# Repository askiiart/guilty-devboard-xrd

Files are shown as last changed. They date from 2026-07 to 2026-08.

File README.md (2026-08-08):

# Guilty Devboard Xrd

A dev board for my keyboard, because all the options kinda suck

- Compatible with both XIAO nRF52840 Plus and nRF54LM20A
- As efficient as possible
- Fast battery charging (configurable ~50-700mA) and over(dis)charge protection
- Up to 5V 3A from USB, and 3.3V 1A (including MCU power draw)
- 27 GPIO pins, nearly as much as the XIAO nRF54LM20A, despite much more limited manufacturing capabilities, while still having an antenna built-in.

See the documentation for more details on what this has over the official XIAOs.

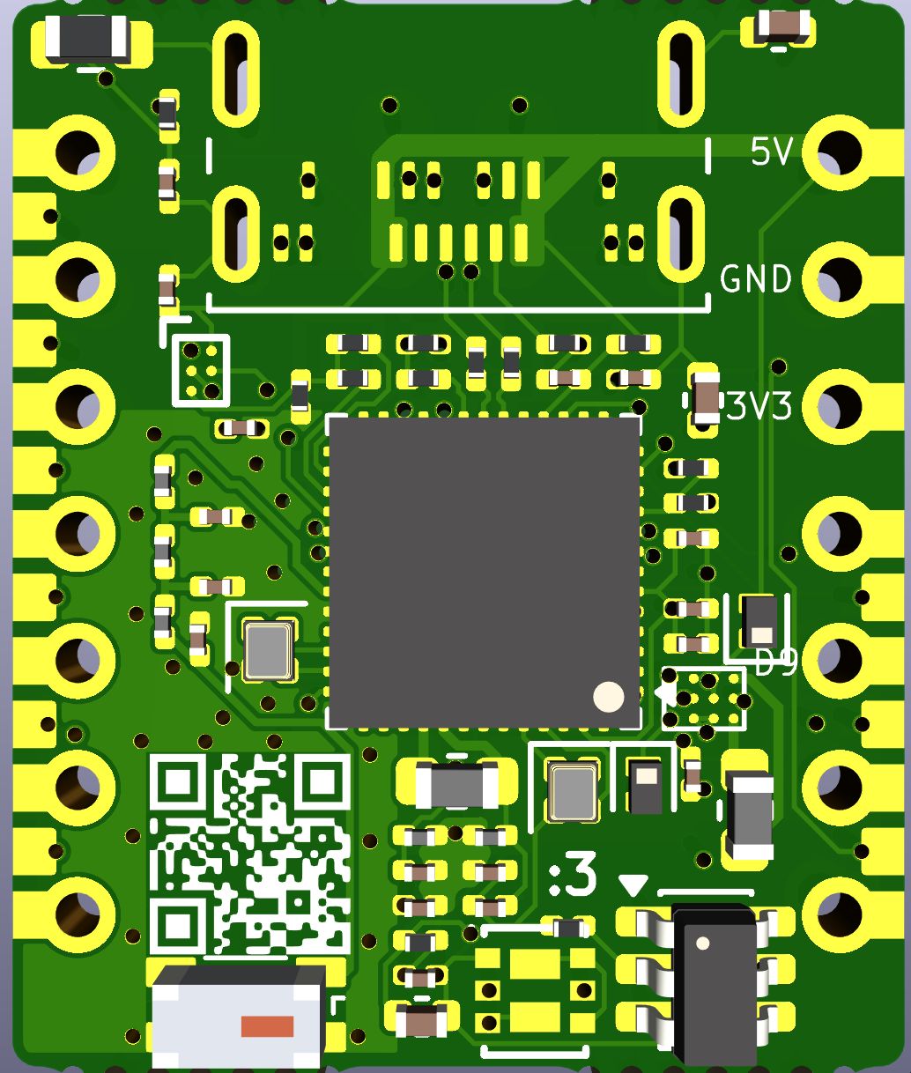
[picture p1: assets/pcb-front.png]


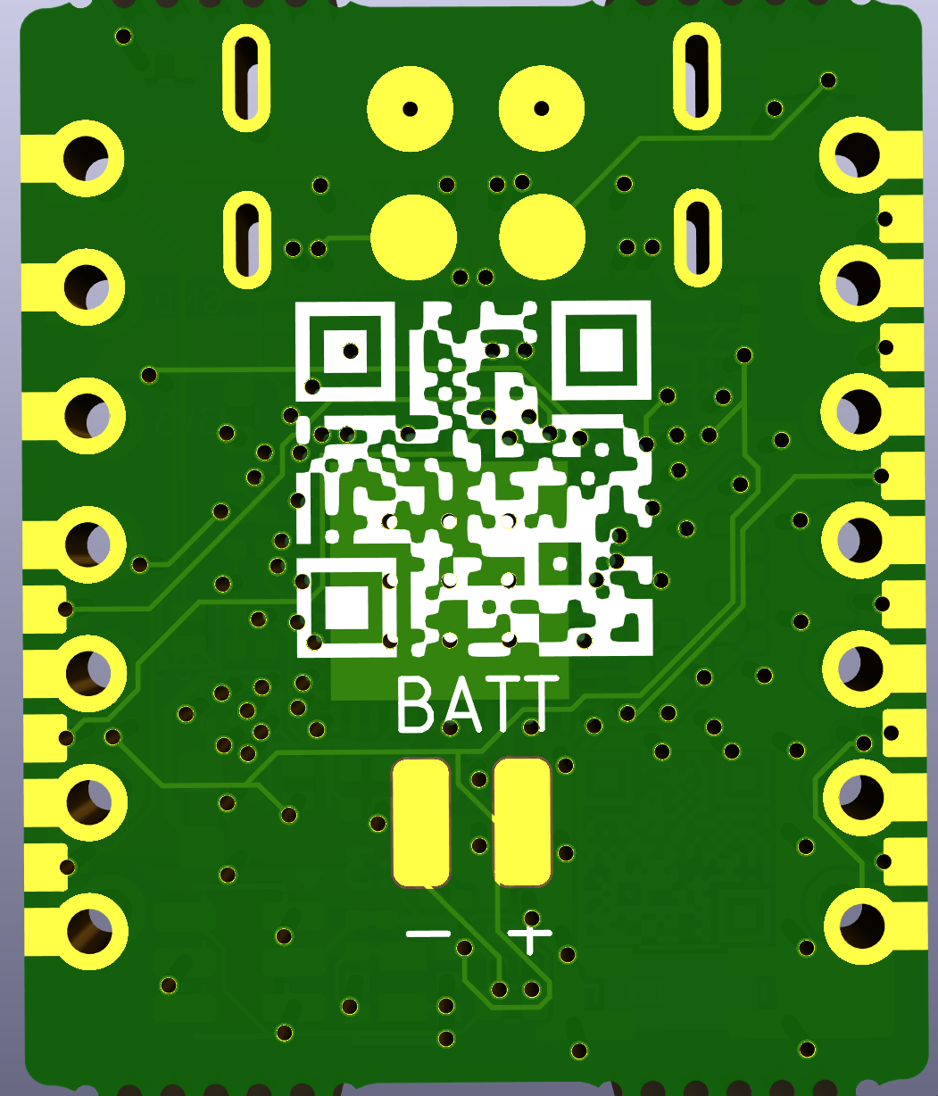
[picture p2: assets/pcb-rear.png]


## Documentation

Docs are available [here](https://askiiart.net/docs/guilty-devboard-xrd.html) ([short link](http://7qq.uk/xrd))

## Note: DRC errors

DRC shows ~140 clearance errors due to the Xiao Plus footprint having pads at and past the edge of the board, a couple things in the keep-out zone, and the QR codes overlapping/being too close to other items. That's intentional, ignore those.

## Schematic

Use Kicanvas to see the [schematic](https://kicanvas.org/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)

## Bill of Materials

|Name |Quantity needed|MOQ|Price |Quantity to order|Link |Total |
|---|---|---|---|---|---|---|
|Diodes |2 |20 |0.0257|20 |<https://www.lcsc.com/product-detail/C2912031.html> |0.514 |
|Ferrite bead |2 |50 |0.025 |50 |<https://www.lcsc.com/product-detail/C525479.html> |1.25 |
|MOSFETs |1 |10 |0.0434|10 |<https://www.lcsc.com/product-detail/C41355091.html> |0.434 |
|100nF cap |5 |50 |0.0018|50 |<https://www.lcsc.com/product-detail/C2903664.html> |0.09 |
|4.7uF cap |4 |10 |0.0733|10 |<https://www.lcsc.com/product-detail/C335103.html> |0.733 |
|1pF cap |1 |100|0.0024|100 |<https://www.lcsc.com/product-detail/C85894.html> |0.24 |
|2.2uF cap |2 |50 |0.0346|50 |<https://www.lcsc.com/product-detail/C335106.html> |1.73 |
|10uF cap |1 |20 |0.0368|20 |<https://www.lcsc.com/product-detail/C76991.html> |0.736 |
|1.5pF cap |1 |100|0.003 |100 |<https://www.lcsc.com/product-detail/C284990.html> |0.3 |
|22uF cap |2 |5  |0.1522|5 |<https://www.lcsc.com/product-detail/C7432764.html> |0.761 |
|470nF cap |1 |100|0.0057|100 |<https://www.lcsc.com/product-detail/C326573.html> |0.57 |
|1.2pF cap |1 |100|0.0016|100 |<https://www.lcsc.com/product-detail/C22374839.html> |0.16 |
|3.3nF inductor |1 |100|0.0073|100 |<https://www.lcsc.com/product-detail/C98045.html> |0.73 |
|1.5uH inductor |1 |50 |0.0111|50 |<https://www.lcsc.com/product-detail/C2885839.html> |0.555 |
|4.7nH inductor |1 |100|0.0099|100 |<https://www.lcsc.com/product-detail/C86126.html> |0.99 |
|3.6nH inductor |1 |20 |0.0322|20 |<https://www.lcsc.com/product-detail/C237447.html> |0.644 |
|4.7uH inductor |1 |1  |0.2829|1 |<https://www.lcsc.com/product-detail/C7261423.html> |0.2829 |
|1nH inductor |1 |100|0.0029|100 |<https://www.lcsc.com/product-detail/C46607389.html> |0.29 |
|5.1k resistor |2 |100|0.0007|100 |<https://www.lcsc.com/product-detail/C473460.html> |0.07 |
|470k resistor |1 |100|0.0013|100 |<https://www.lcsc.com/product-detail/C54530578.html> |0.13 |
|30 ohm resistor |2 |100|0.0008|100 |<https://www.lcsc.com/product-detail/C320826.html> |0.08 |
|2k resistor |1 |100|0.0021|100 |<https://www.lcsc.com/product-detail/C138107.html> |0.21 |
|1k resistor |1 |100|0.001 |100 |<https://www.lcsc.com/product-detail/C131396.html> |0.1 |
|806k resistor |1 |100|0.0009|100 |<https://www.lcsc.com/product-detail/C474840.html> |0.09 |
|2M resistor |1 |100|0.0006|100 |<https://www.lcsc.com/product-detail/C138106.html> |0.06 |
|10k resistor |1 |100|0.001 |100 |<https://www.lcsc.com/product-detail/C138117.html> |0.1 |
|220k resistor |1 |100|0.003 |100 |<https://www.lcsc.com/product-detail/C142020.html> |0.3 |
|68k resistor |1 |100|0.003 |100 |<https://www.lcsc.com/product-detail/C274345.html> |0.3 |
|2.2 ohm resistor |1 |100|0.0037|100 |<https://www.lcsc.com/product-detail/C473517.html> |0.37 |
|200 ohm resistor |1 |100|0.0011|100 |<https://www.lcsc.com/product-detail/C304517.html> |0.11 |
|SGM40567 |1 |1  |0.53  |1 |<https://www.lcsc.com/product-detail/C5141336.html> |0.53 |
|FH9261-G3JH |1 |20 |0.0289|20 |<https://www.lcsc.com/product-detail/C19273258.html> |0.578 |
|BD83070GWL-E2 |1 |1  |0.7198|1 |<https://www.lcsc.com/product-detail/C2071126.html> |0.7198 |
|32MHz crystal |1 |5  |1.0134|1 |<https://www.lcsc.com/product-detail/C5203637.html> |1.0134 |
|32.768kHz crystal |1 |1  |3.0197|1 |<https://www.lcsc.com/product-detail/C2595065.html> |3.0197 |
| | | | | | | |
|2450AT18D0100001E |1 |1  |0.57  |1 |<https://www.digikey.com/en/products/detail/johanson-technology-inc/2450AT18D0100001E/4770685> |0.57 |
| | | | | | | |
|NRF54LM20A-QGAA-R |1 |1  |6.7 |1 |<https://mou.sr/44t4RAm> |6.7 |
|Amphenol 124019772112A (USB-C)|1 |1  |2.41  |1 |<https://www.mouser.com/ProductDetail/Amphenol-Commercial-Products/124019772112A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>|2.41 |
| | | | | | | |
|JLCPCB | | | | | |$15.10 |
| | | | | | | |
|JLCPCB shipping | | | | |Roughly |$9.79 |
|Digikey shipping | | | | | |$4.99 |
|LCSC shipping | | | | | |7.25 |
|Mouser shipping | | | | | |8.49 |
|Mouser estimated tariffs | | | | | |0.24 |
| | | | | | | |
|Subtotal | | | | | |74.3308  |
|Total | | | | | |80.463091|

## Production notes

The layer stackup should be JLC0616H-3313, and a stencil with electropolishing is recommended.

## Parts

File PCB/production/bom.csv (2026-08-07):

Designator | Footprint | Quantity | Value | LCSC Part #
AE1 | 2450AT18D0100001E_L | 1 | Antenna_Chip
C1 | 0402 | 1 | 10uF
C11, C14, C17, C4 | 0201 | 4 | 4.7uF
C12 | 0201 | 1 | 0.1uF
C13, C6 | 0201 | 2 | 2.2uF
C15 | 0201 | 1 | 1.5pF
C16, C19 | 0402 | 2 | 22uF
C18 | 0201 | 1 | 1.2pF
C2, C21, C8, C9 | 0201 | 4 | 100nF
C23 | 0201 | 1 | 0.47uF
C3, C7 | 0201 | 2 | DNP
C5 | 0201 | 1 | 1.0pF
D6, D7 | D_SOD-882 | 2 | D
FB1, FB2 | 0201 | 2 | FerriteBead
J1 | USB_C_Receptacle_Amphenol_124019772112A | 1 | USB_C_Receptacle_USB2.0_16P
JP1 | 0603 | 1 | Jumper_2_Open
L1 | 0201 | 1 | 3.3nH
L3 | 0603 | 1 | 1.5uH
L4 | 0201 | 1 | 4.7nH
L5 | 0201 | 1 | 3.6nH
L6 | 0402 | 1 | 4.7uH
L7 | 0201 | 1 | 1.0nH
Q1 | PDFN-6_L2.0-W2.0-P0.65-BL-EP-1 | 1 | SP2038CNQ | C41355091
R1, R2 | 0201 | 2 | 5.1k
R12 | 0201 | 1 | 10k
R14 | 0201 | 1 | 220k
R15 | 0201 | 1 | 68k
R16 | 0201 | 1 | 2.2
R17 | 0201 | 1 | 200
R3 | 0201 | 1 | 470k
R4, R5 | 0201 | 2 | 30
R6 | 0201 | 1 | 2k
R7 | 0201 | 1 | 1k
R8 | 0201 | 1 | 806k
R9 | 0201 | 1 | 2M
U1 | QFN-52-1EP_6x6mm_P0.4mm_EP4.7x4.7mm_ThermalVias | 1 | nRF54LM20A-QGAA
U2 | WLCSP-6_L1.2-W0.9-R3-C2-P0.40-TL | 1 | SGM40567-4.2XG/TR | C5141336
U4 | TCA9536 | 1 | TCA9536
U5 | SOT-23-6 | 1 | FH9261-G3JH
U6 | BD83070GWL | 1 | BD83070GWL-E2
Y1 | Crystal_SMD_1210-4Pin_1.2x1.0mm | 1 | 32MHz
Y2 | Crystal_SMD_1210-4Pin_1.2x1.0mm | 1 | 32.768kHz

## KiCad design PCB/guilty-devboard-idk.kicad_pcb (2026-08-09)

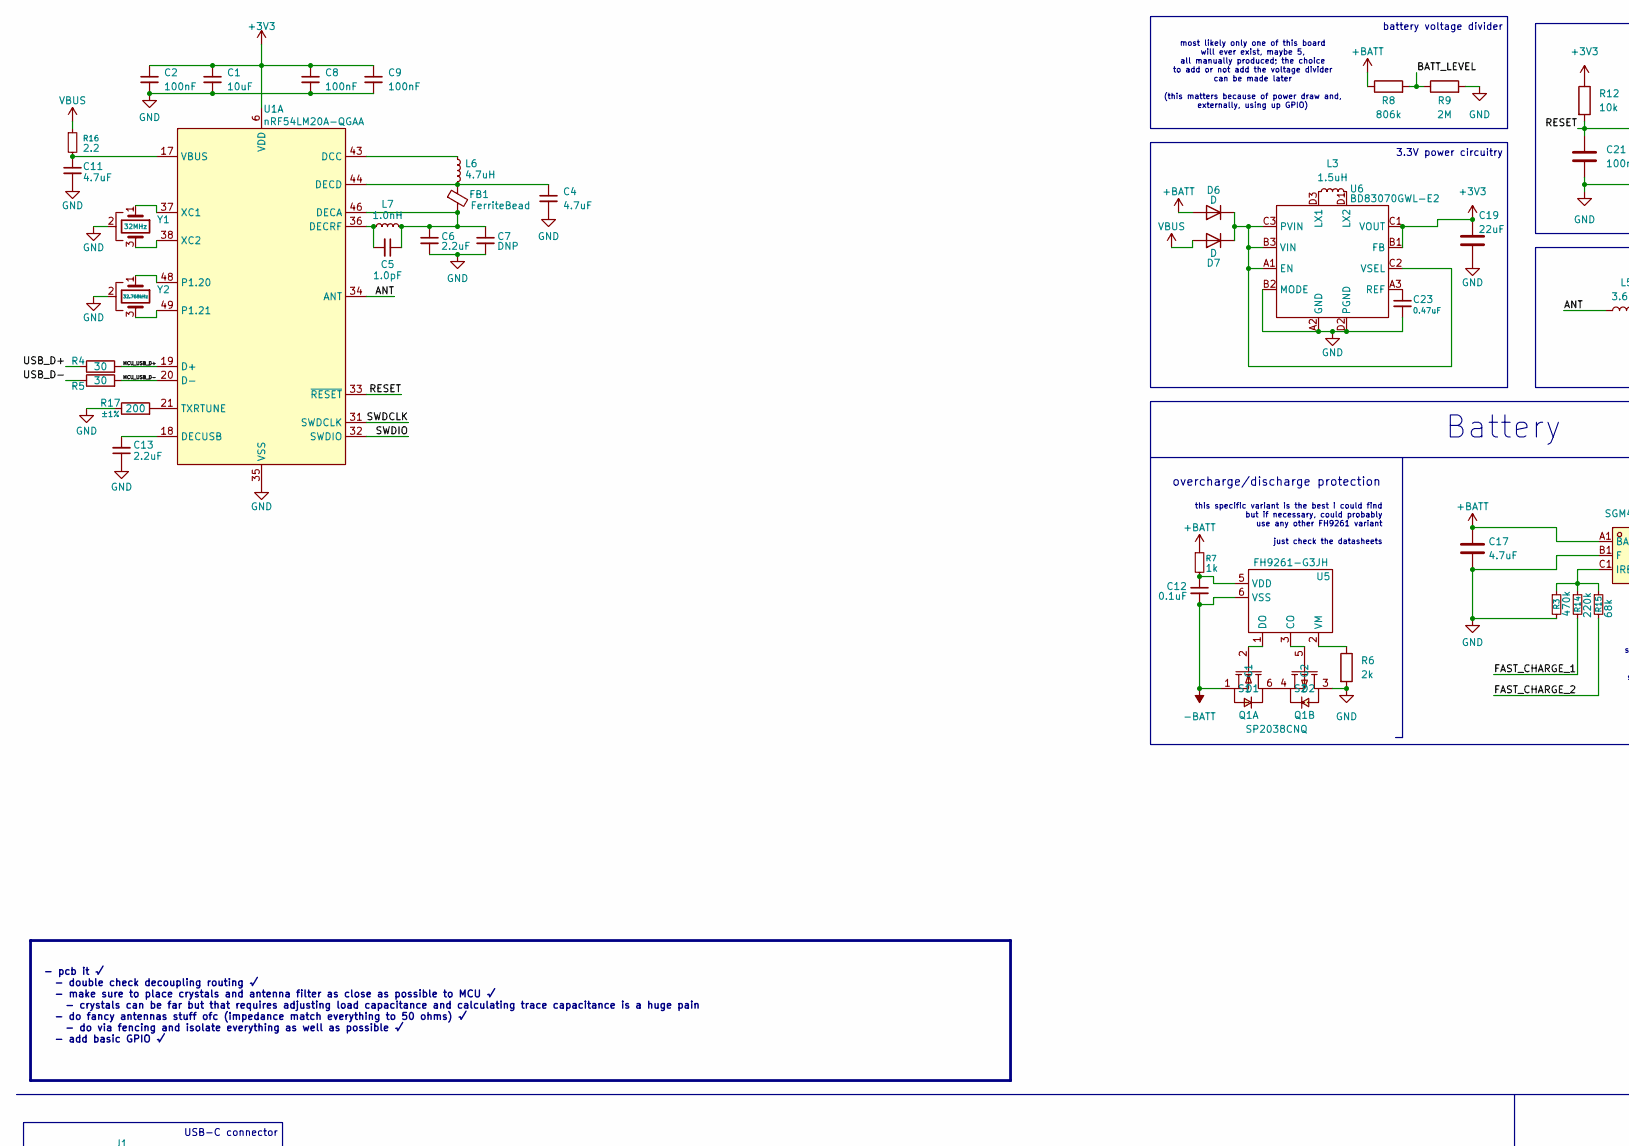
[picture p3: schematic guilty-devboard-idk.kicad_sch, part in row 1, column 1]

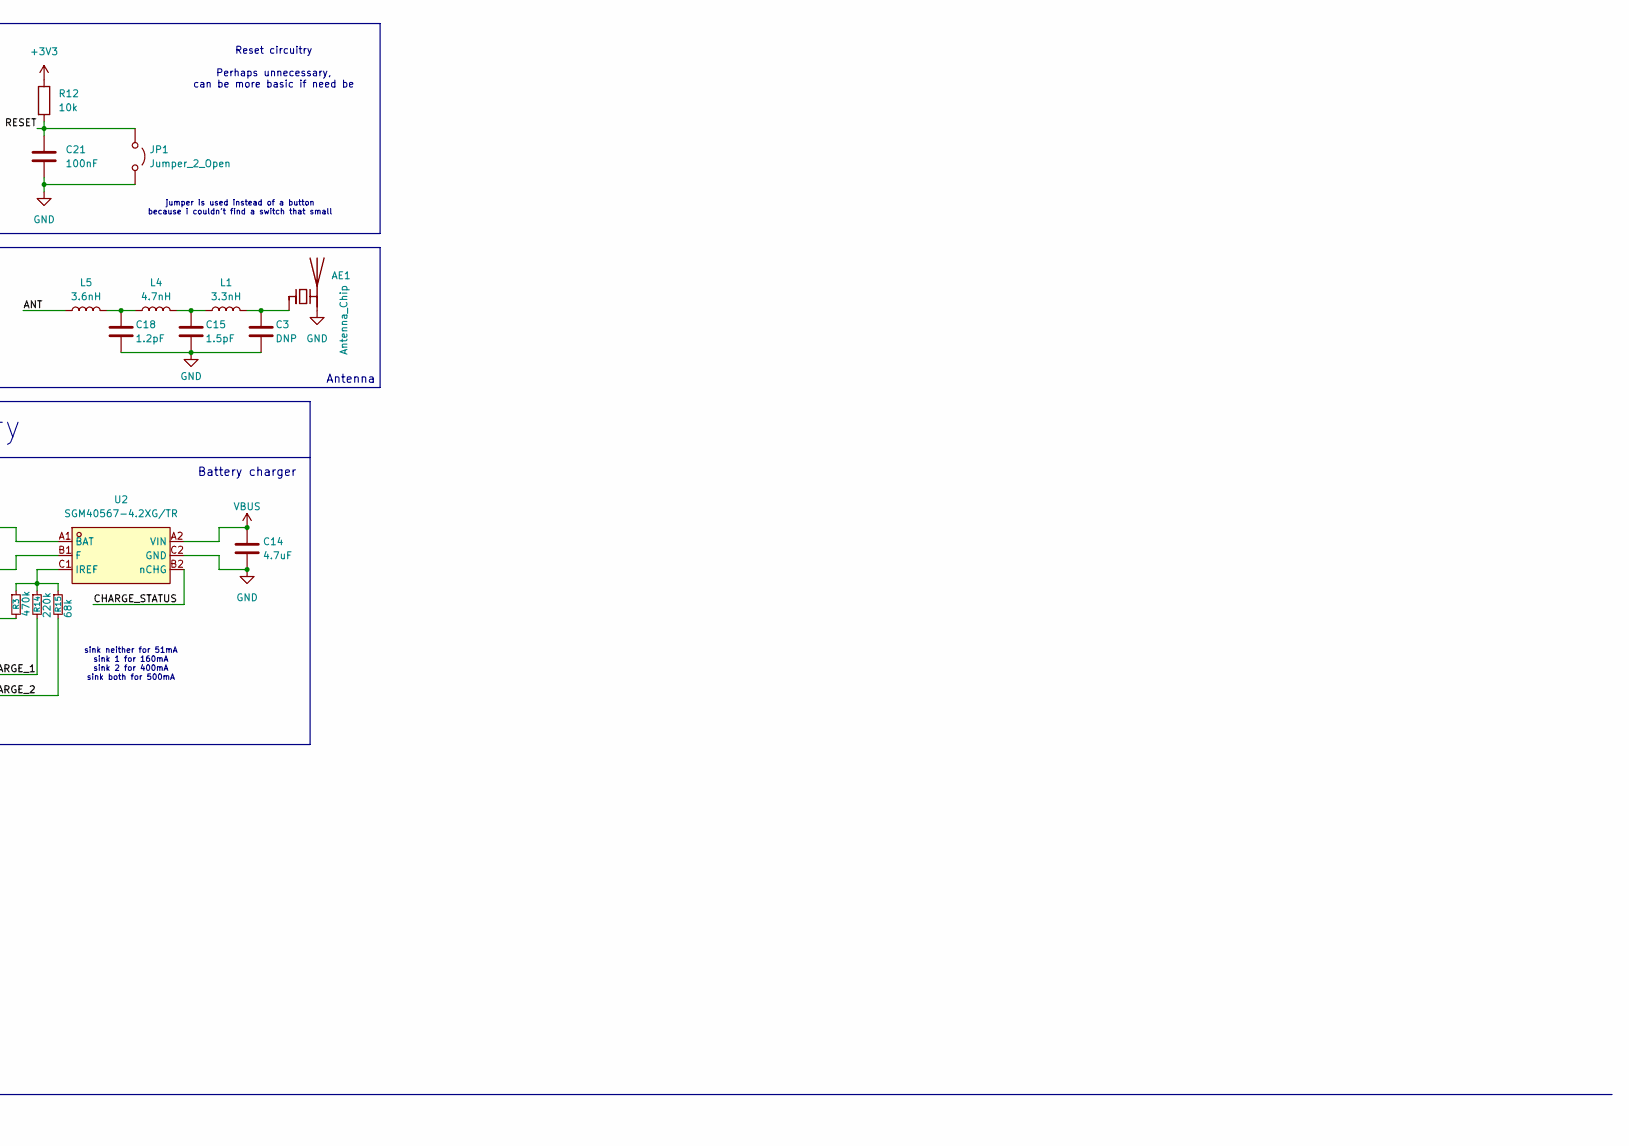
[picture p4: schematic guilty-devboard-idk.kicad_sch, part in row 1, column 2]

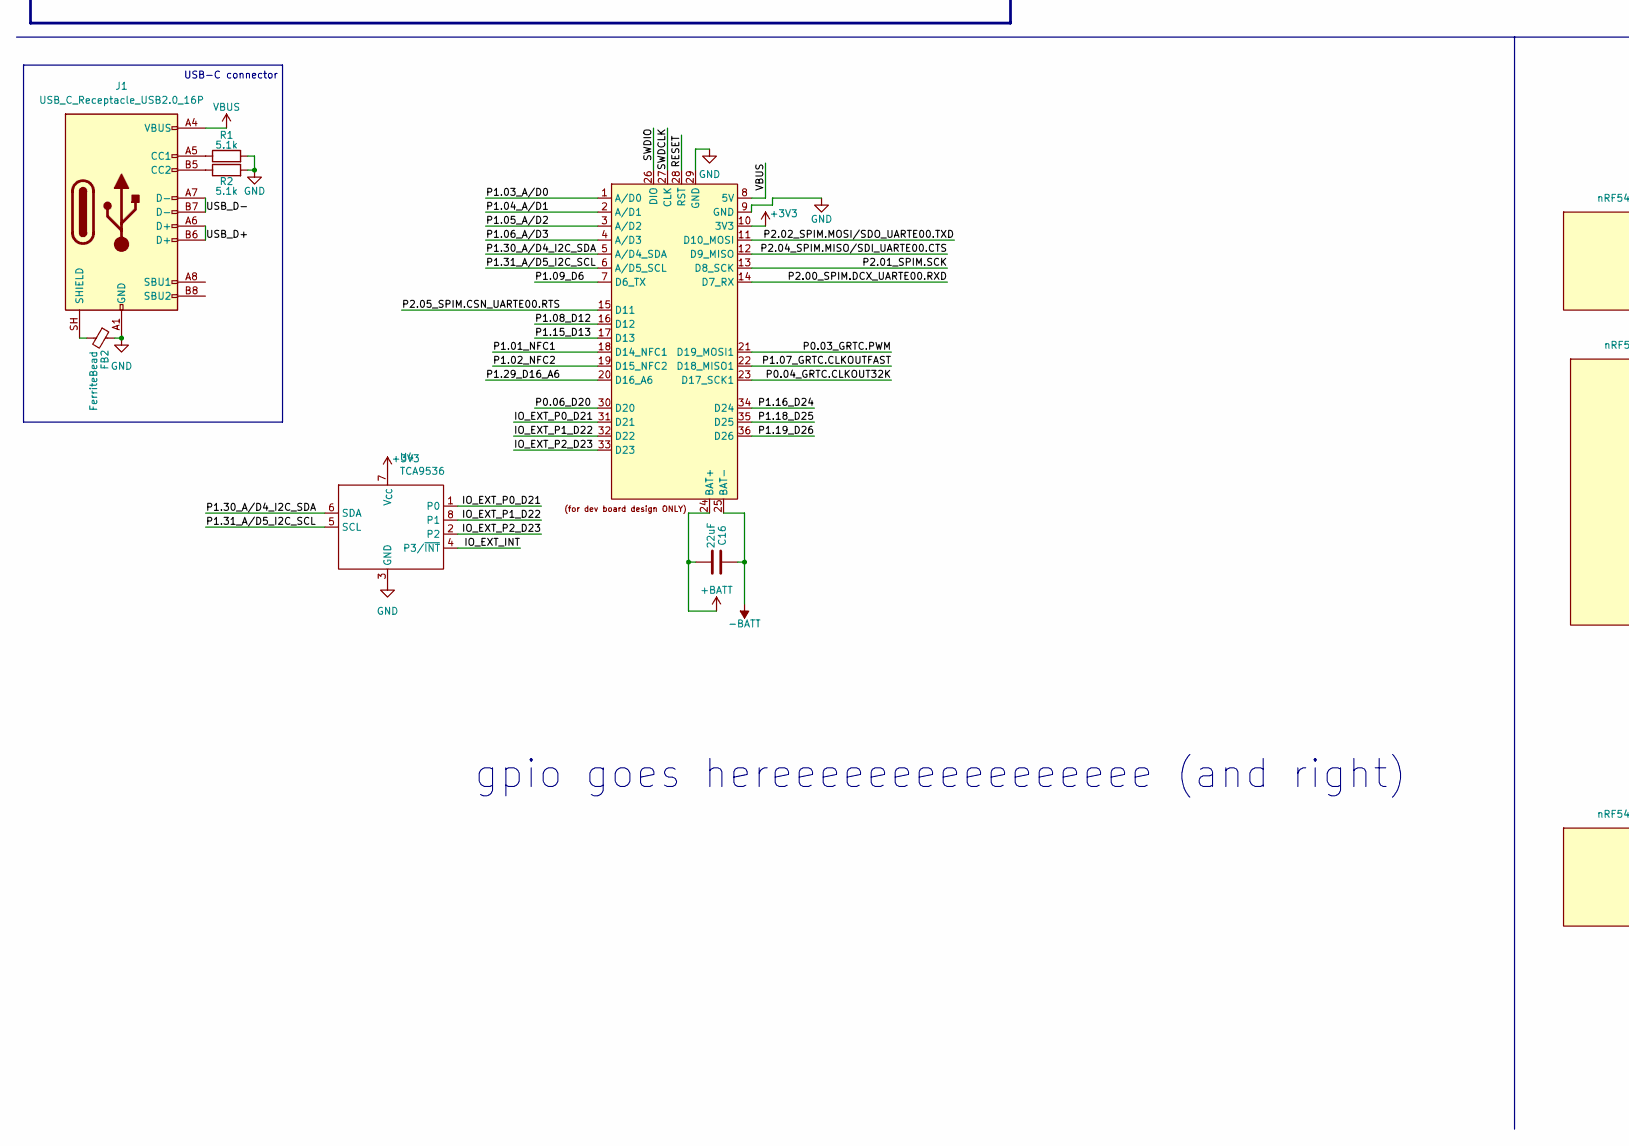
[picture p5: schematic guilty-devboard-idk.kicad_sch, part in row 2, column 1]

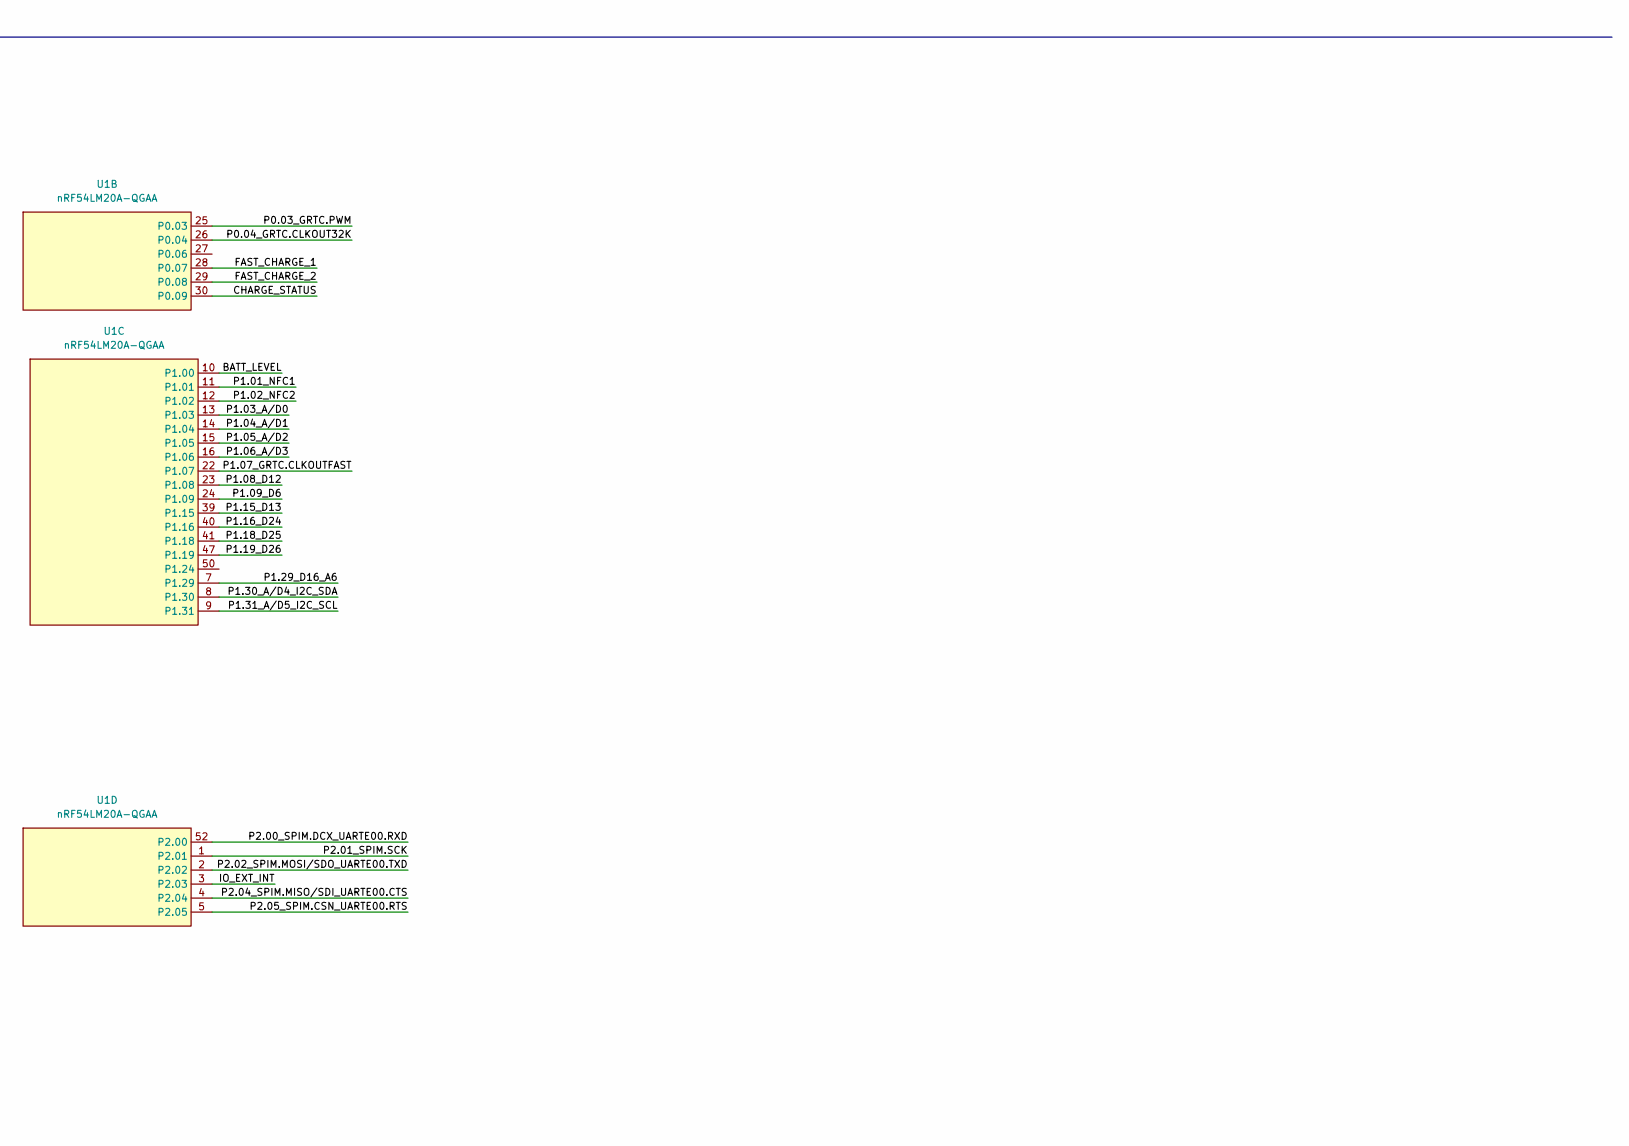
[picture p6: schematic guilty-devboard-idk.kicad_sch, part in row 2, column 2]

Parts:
AE1: Antenna_Chip; 2450AT18D0100001E_L
C1: 10uF; C_0402_1005Metric
C2, C8, C9, C21: 100nF; C_0201_0603Metric
C3, C7: DNP; C_0201_0603Metric
C4, C11, C14, C17: 4.7uF; C_0201_0603Metric
C5: 1.0pF; C_0201_0603Metric
C6, C13: 2.2uF; C_0201_0603Metric
C12: 0.1uF; C_0201_0603Metric
C15: 1.5pF; C_0201_0603Metric
C16, C19: 22uF; C_0402_1005Metric
C18: 1.2pF; C_0201_0603Metric
C23: 0.47uF; C_0201_0603Metric
D6, D7: D; D_SOD-882
FB1, FB2: FerriteBead; L_0201_0603Metric
J1: USB_C_Receptacle_USB2.0_16P; USB_C_Receptacle_Amphenol_124019772112A
JP1: Jumper_2_Open; R_0603_1608Metric
L1: 3.3nH; L_0201_0603Metric
L3: 1.5uH; L_0603_1608Metric
L4: 4.7nH; L_0201_0603Metric
L5: 3.6nH; L_0201_0603Metric
L6: 4.7uH; L_0402_1005Metric
L7: 1.0nH; L_0201_0603Metric
Q1: SP2038CNQ; PDFN-6_L2.0-W2.0-P0.65-BL-EP-1; LCSC Part C41355091
R1, R2: 5.1k; R_0201_0603Metric
R3: 470k; R_0201_0603Metric
R4, R5: 30; R_0201_0603Metric
R6: 2k; R_0201_0603Metric
R7: 1k; R_0201_0603Metric
R8: 806k; R_0201_0603Metric
R9: 2M; R_0201_0603Metric
R12: 10k; R_0201_0603Metric
R14: 220k; R_0201_0603Metric
R15: 68k; R_0201_0603Metric
R16: 2.2; R_0201_0603Metric
R17: 200; R_0201_0603Metric; Tolerance ±1%
U1: nRF54LM20A-QGAA; QFN-52-1EP_6x6mm_P0.4mm_EP4.7x4.7mm_ThermalVias
U2: SGM40567-4.2XG/TR; WLCSP-6_L1.2-W0.9-R3-C2-P0.40-TL; LCSC Part C5141336
U3: Xiao nRF52840 Connectors; Guilty Devboard Xrd pads
U4: TCA9536
U5: FH9261-G3JH; SOT-23-6
U6: BD83070GWL-E2; BD83070GWL
Y1: 32MHz; Crystal_SMD_1210-4Pin_1.2x1.0mm
Y2: 32.768kHz; Crystal_SMD_1210-4Pin_1.2x1.0mm

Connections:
+3V3: C1.1, C2.1, C8.1, C9.1, C19.1, R12.1, U1.6 (VDD), U1.42 (VDD), U1.51 (VDD), U3.10 (3V3), U4.7 (V_{CC}), U6.B1 (FB), U6.C1 (VOUT)
+BATT: C16.2, C17.1, D6.2 (A), R7.1, R8.1, U2.A1 (BAT), U3.24 (BAT+)
-BATT: C12.2, C16.1, Q1.1 (S1), U3.25 (BAT-), U5.6 (VSS)
/ANT: L5.1, U1.34 (ANT)
/BATT_LEVEL: R8.2, R9.1, U1.10 (P1.00)
/CHARGE_STATUS: U1.30 (P0.09), U2.B2 (nCHG)
/FAST_CHARGE_1: R14.2, U1.28 (P0.07)
/FAST_CHARGE_2: R15.2, U1.29 (P0.08)
/IO_EXT_INT: U1.3 (P2.03), U4.4 (P3/~INT)
/IO_EXT_P0_D21: U3.31 (D21), U4.1 (P0)
/IO_EXT_P1_D22: U3.32 (D22), U4.8 (P1)
/IO_EXT_P2_D23: U3.33 (D23), U4.2
/MCU_USB_D+: R4.2, U1.19 (D+)
/MCU_USB_D-: R5.2, U1.20 (D-)
/P0.03_GRTC.PWM: U1.25 (P0.03), U3.21 (D19_MOSI1)
/P0.04_GRTC.CLKOUT32K: U1.26 (P0.04), U3.23 (D17_SCK1)
/P0.06_D20: U3.30 (D20)
/P1.01_NFC1: U1.11 (P1.01), U3.18 (D14_NFC1)
/P1.02_NFC2: U1.12 (P1.02), U3.19 (D15_NFC2)
/P1.03_A/D0: U1.13 (P1.03), U3.1 (A/D0)
/P1.04_A/D1: U1.14 (P1.04), U3.2 (A/D1)
/P1.05_A/D2: U1.15 (P1.05), U3.3 (A/D2)
/P1.06_A/D3: U1.16 (P1.06), U3.4 (A/D3)
/P1.07_GRTC.CLKOUTFAST: U1.22 (P1.07), U3.22 (D18_MISO1)
/P1.08_D12: U1.23 (P1.08), U3.16 (D12)
/P1.09_D6: U1.24 (P1.09), U3.7 (D6_TX)
/P1.15_D13: U1.39 (P1.15), U3.17 (D13)
/P1.16_D24: U1.40 (P1.16), U3.34 (D24)
/P1.18_D25: U1.41 (P1.18), U3.35 (D25)
/P1.19_D26: U1.47 (P1.19), U3.36 (D26)
/P1.29_D16_A6: U1.7 (P1.29), U3.20 (D16_A6)
/P1.30_A/D4_I2C_SDA: U1.8 (P1.30), U3.5 (A/D4_SDA), U4.6 (SDA)
/P1.31_A/D5_I2C_SCL: U1.9 (P1.31), U3.6 (A/D5_SCL), U4.5 (SCL)
/P2.00_SPIM.DCX_UARTE00.RXD: U1.52 (P2.00), U3.14 (D7_RX)
/P2.01_SPIM.SCK: U1.1 (P2.01), U3.13 (D8_SCK)
/P2.02_SPIM.MOSI/SDO_UARTE00.TXD: U1.2 (P2.02), U3.11 (D10_MOSI)
/P2.04_SPIM.MISO/SDI_UARTE00.CTS: U1.4 (P2.04), U3.12 (D9_MISO)
/P2.05_SPIM.CSN_UARTE00.RTS: U1.5 (P2.05), U3.15 (D11)
/RESET: C21.1, JP1.1 (A), R12.2, U1.33 (~RESET), U3.28 (RST)
/SWDCLK: U1.31 (SWDCLK), U3.27 (CLK)
/SWDIO: U1.32 (SWDIO), U3.26 (DIO)
/USB_D+: J1.A6 (D+), J1.B6 (D+), R4.1
/USB_D-: J1.A7 (D-), J1.B7 (D-), R5.1
GND: AE1.2 (PCB_Trace), C1.2, C2.2, C3.1, C4.2, C6.2, C7.2, C8.2, C9.2, C11.2, C13.1, C14.2, C15.1, C17.2, C18.1, C19.2, C21.2, C23.2, FB2.1, J1.A1 (GND), J1.A12 (GND), J1.B1 (GND), J1.B12 (GND), JP1.2 (B), Q1.3 (D2), R1.2, R2.2, R3.2, R6.2, R9.2, R17.1, U1.35 (VSS), U1.45 (VSS), U1.53 (VSS), U2.B1 (F), U2.C2 (GND), U3.9 (GND), U3.29 (GND), U4.3 (GND), U6.A2 (GND), U6.B2 (MODE), U6.D2 (PGND), Y1.2, Y2.2
unnamed: AE1.1 (FEED), C3.2, L1.2
unnamed: C15.2, L1.1, L4.2
unnamed: C18.2, L4.1, L5.2
unnamed: D6.1 (K), D7.1 (K), U6.A1 (EN), U6.B3 (VIN), U6.C2 (VSEL), U6.C3 (PVIN)
unnamed: J1.A5 (CC1), R1.1
unnamed: J1.B5 (CC2), R2.1
unnamed: FB2.2, J1.SH (SHIELD)
unnamed: Q1.4 (S2), Q1.6 (D1)
unnamed: Q1.2 (G1), U5.1 (DO)
unnamed: Q1.5 (G2), U5.3 (CO)
unnamed: L6.1, U1.43 (DCC)
unnamed: C5.1, C6.1, C7.1, FB1.2, L7.2, U1.46 (DECA)
unnamed: C4.1, FB1.1, L6.2, U1.44 (DECD)
unnamed: C5.2, L7.1, U1.36 (DECRF)
unnamed: C13.2, U1.18 (DECUSB)
unnamed: U1.48 (P1.20), Y2.1
unnamed: U1.49 (P1.21), Y2.3
unnamed: R17.2, U1.21 (TXRTUNE)
unnamed: C11.1, R16.2, U1.17 (VBUS)
unnamed: U1.37 (XC1), Y1.1
unnamed: U1.38 (XC2), Y1.3
unnamed: R3.1, R14.1, R15.1, U2.C1 (IREF)
unnamed: C12.1, R7.2, U5.5 (VDD)
unnamed: R6.1, U5.2 (VM)
unnamed: L3.1, U6.D3 (LX1)
unnamed: L3.2, U6.D1 (LX2)
unnamed: C23.1, U6.A3 (REF)
VBUS: C14.1, D7.2 (A), J1.A4 (VBUS), J1.A9 (VBUS), J1.B4 (VBUS), J1.B9 (VBUS), R16.1, U2.A2 (VIN), U3.8 (5V)

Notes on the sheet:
Reset circuitry Perhaps unnecessary, can be more basic if need be
Battery charger
battery voltage divider
- pcb it √ - double check decoupling routing √ - make sure to place crystals and antenna filter as close as possible to MCU √ - crystals can be far but that requires adjusting load capacitance and calculating trace capacitance is a huge pain - do fancy antennas stuff ofc (impedance match everything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
jumper is used instead of a button because i couldn't find a switch that small
this specific variant is the best i could find but if necessary, could probably use any other FH9261 variant just check the datasheets
Antenna
USB-C connector
gpio goes hereeeeeeeeeeeeeeee (and right)
Battery
overcharge/discharge protection
3.3V power circuitry
sink neither for 51mA sink 1 for 160mA sink 2 for 400mA sink both for 500mA
most likely only one of this board will ever exist, maybe 5, all manually produced; the choice to add or not add the voltage divider can be made later (this matters because of power draw and, externally, using up GPIO)

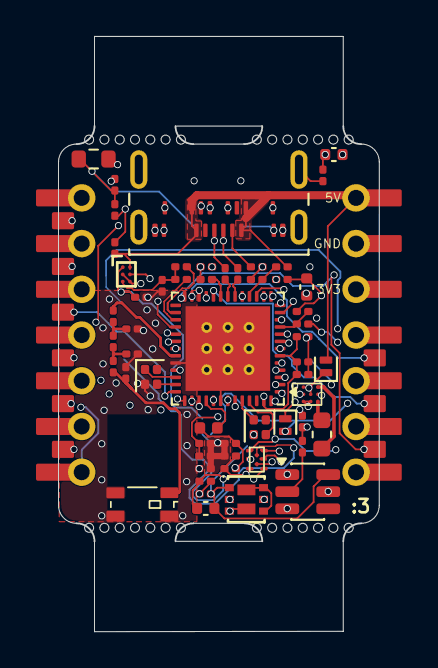
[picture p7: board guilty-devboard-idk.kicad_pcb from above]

Board: 6 copper layers, 17.8 x 33.1 mm, 56 parts (0 on the bottom side), 71 nets.

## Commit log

2026-05-04 commit idk pre-10.0 update
    [guilty-devboard-idk.kicad_pcb, guilty-devboard-idk.kicad_sch]
2026-05-09 update idk schematic is done aside from switching out 3.3V
    [guilty-devboard-idk.kicad_pcb, guilty-devboard-idk.kicad_sch]
2026-05-20 idk pretty much finish schematic everything should be right, besides adding more basic gpio when convenient
    [guilty-devboard-idk.kicad_sch]
2026-05-25 terrible half done routing idk - post-decent filter routing
    [guilty-devboard-idk.kicad_pcb, guilty-devboard-idk.kicad_sch]
2026-05-27 fully routed
    [guilty-devboard-idk.kicad_pcb, guilty-devboard-idk.kicad_sch]
2026-05-28 update routing to make antenna better
    [guilty-devboard-idk.kicad_pcb, guilty-devboard-idk.kicad_sch]
2026-06-04 update readme a bit
    [guilty-devboard-idk.kicad_pcb]
2026-06-06 improve via fencing and make it slightly longer for tolerance
    [guilty-devboard-idk.kicad_pcb]
2026-06-14 misc notes and whatnot on schematic, got rid of unnecessary via/GNDed pin
    [guilty-devboard-idk.kicad_pcb, guilty-devboard-idk.kicad_sch]
2026-06-22 add 5mm edges for pcba
    [guilty-devboard-idk.kicad_pcb, guilty-devboard-idk.kicad_sch]
2026-06-24 add BOM
    [BOM.csv, BOM.ods, guilty-devboard-idk.kicad_pcb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]
2026-07-25 use way smaller crystals and redo with space for bigger cap/inductor
    [BOM.csv, BOM.ods, guilty-devboard-idk.kicad_pcb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]
2026-07-25 reroute antenna/rf filter
    [guilty-devboard-idk.kicad_pcb]
2026-07-25 tbh i have no idea what i cchanged but uh sure commit why not
    [guilty-devboard-idk.kicad_pcb, guilty-devboard-idk.kicad_sch]
2026-07-26 update BOM
    [BOM.csv, BOM.ods]
2026-07-26 why do i need production files even stasis didn't require that
    [bom.csv, designators.csv, positions.csv]
2026-07-27 add TCA9536 footprint
2026-07-31 add tca9536 symbol and to schematic and whatever
    [guilty-devboard-idk.kicad_sch]
2026-07-31 add updated TCA9536 footprint (i dont know why it's updated tbh), and updated devboard symbol/footprint for xiao nrf54lm20a pads
    [guilty-devboard-idk.kicad_pcb, guilty-devboard-idk.kicad_sch]
2026-08-04 route tca9536 and stuffffff
    [BOM.csv, BOM.ods, guilty-devboard-idk.kicad_pcb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]
2026-08-04 add ferrite bead to shield usb-c
    [BOM.csv, guilty-devboard-idk.kicad_pcb, guilty-devboard-idk.kicad_sch]
2026-08-04 improve qr code
    [guilty-devboard-idk.kicad_pcb]
2026-08-06 update qr codes with link shortener, fix footprint, update bom with antenna
    [BOM.csv, BOM.ods, guilty-devboard-idk.kicad_pcb]
2026-08-06 remove vbus zone, fix drc errors
    [guilty-devboard-idk.kicad_pcb]
2026-08-07 fix bom? idek how it got messed up
    [BOM.csv, BOM.ods]
2026-08-07 update production files
    [bom.csv, designators.csv, positions.csv]
2026-08-09 increase corner rounding
    [guilty-devboard-idk.kicad_pcb]
2026-10-20 add schematic
2026-11-06 update with different charging speeds/resistors to account for gpio resistance
2026-11-07 fix slightly off antenna trace width
